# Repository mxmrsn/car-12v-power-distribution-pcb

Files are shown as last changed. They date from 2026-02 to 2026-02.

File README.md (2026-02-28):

# Car 12V Power Distribution PCB
12V distribution block for supporting interior automotive (12V+) accessories. Note: Some accesories mentioned such as dashcam and charger have downstream 5V regulators. Molex PicoSpox contacts (0874370231) are rated for 3A each with 24AWG wire.

## Notes
- Footprints are Molex PicoSpoX-style SMD 1.5mm pitch footprints. 
- Inputs:
  - `12V+` (+12V battery)
  - `12V_ACC` (+12V accessory)
  - `GND` (ground)
- Output (3-pin): `+12V`, `+12V_ACC`, `GND`
- Output (4-pin): `+12V`, `+12V_ACC`, `+12V_HEADLIGHT`, `GND`
- PCB uses 40 mil traces for all nets. 
- Board outline is 1.5" x 2".
- 3D printed caddy will require strain relief and a mobile loop of wire to move with the opening/closing of the drawer.

## Schematic
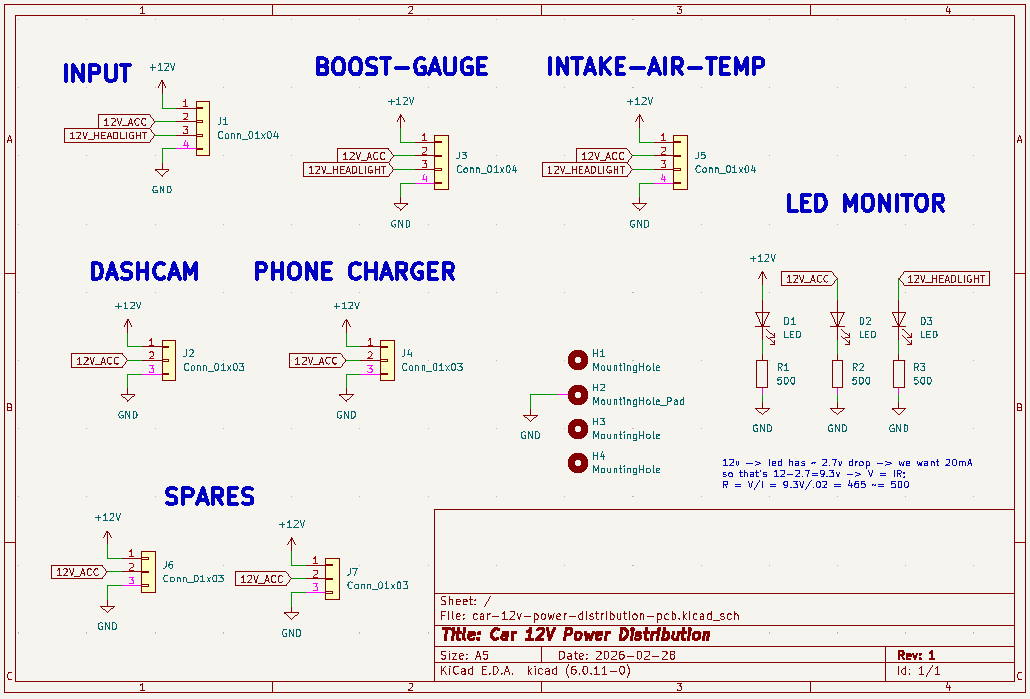
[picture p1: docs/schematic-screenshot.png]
Schematic


## PCB Layout
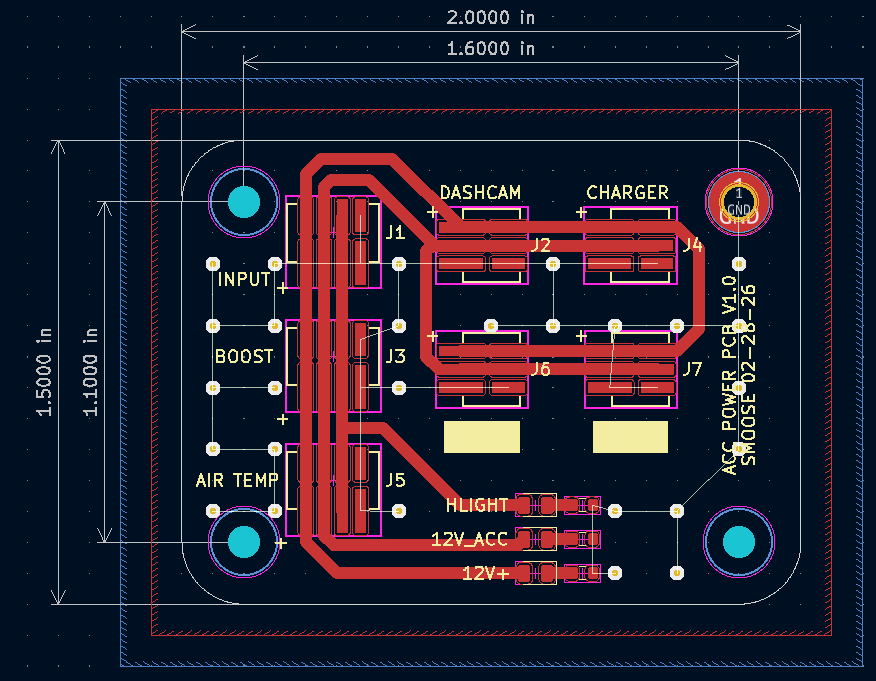
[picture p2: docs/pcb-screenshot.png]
Layout


## 3D Model
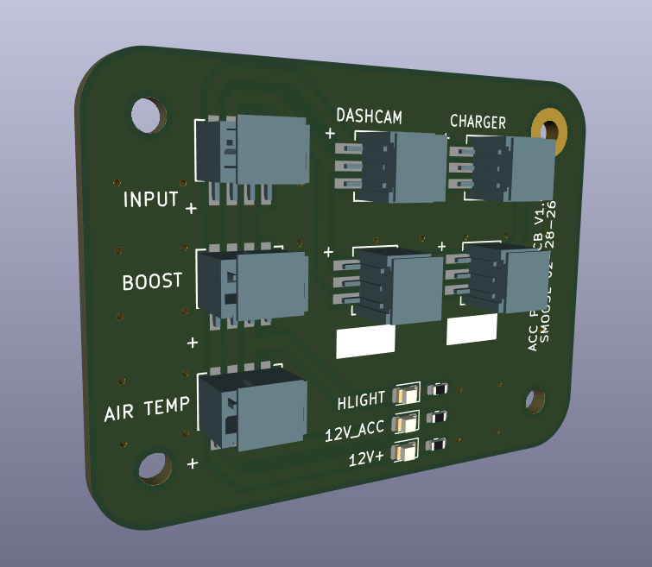
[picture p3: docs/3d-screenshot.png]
3D


## BOM
- 3-pin connector [Molex #0874370363](https://www.digikey.com/en/products/detail/molex/0874370363/2834835)
- 4-pin connector [Molex 0874370473](https://www.digikey.com/en/products/detail/molex/0874370473/2421923)

Mating connectors (cable-side):
- 3-pin housing [Molex #0874390300](https://www.digikey.com/en/products/detail/molex/0874390300/561766)
- 4-pin housing [Molex #0874390400](https://www.digikey.com/en/products/detail/molex/0874390400/561767)
- Molex PicoSpox Contact [Molex #0874210000](https://www.digikey.com/en/products/detail/molex/0874210000/561764)

## Reference
- [Molex PicoSpox Wire-to-Board Connectors](https://www.digikey.com/en/product-highlight/m/molex-connector/pico-spox-wire-to-board-connector-system)

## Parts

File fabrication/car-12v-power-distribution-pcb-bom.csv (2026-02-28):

Comment | Designator | Footprint | LCSC Part #
LED Light emitting diode | D1,D2,D3 | LED_0603_1608Metric | C2286
Conn_01x04 Generic connector, single row, 01x04, script generated (kicad-library-utils/schlib/autogen/connector/) | J1,J3,J5 | CONN_874370231-SD_04_MOL | C588581
Conn_01x03 Generic connector, single row, 01x03, script generated (kicad-library-utils/schlib/autogen/connector/) | J2,J4,J6,J7 | CONN_874370231-SD_03_MOL | C17393004
500 Resistor | R1,R2,R3 | R_0603_1608Metric | C860931

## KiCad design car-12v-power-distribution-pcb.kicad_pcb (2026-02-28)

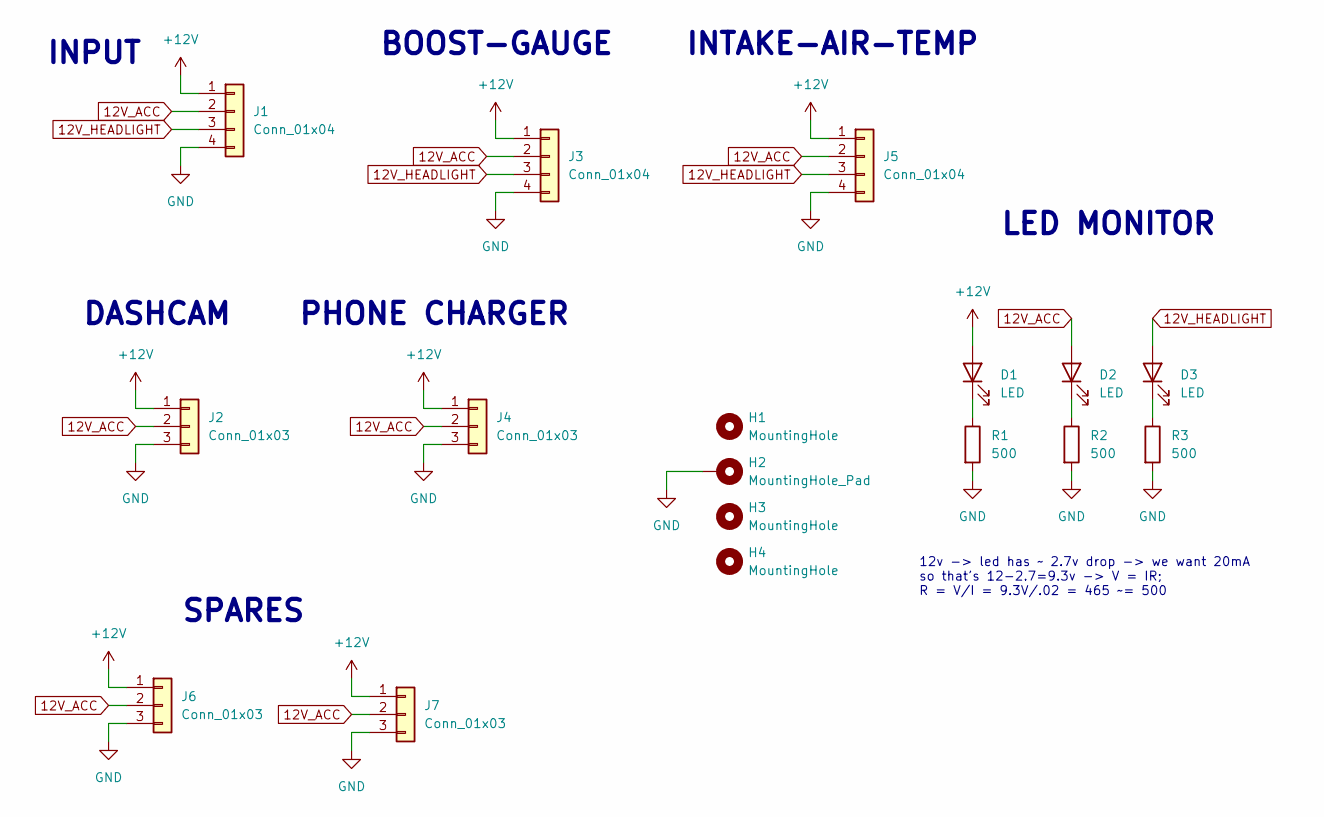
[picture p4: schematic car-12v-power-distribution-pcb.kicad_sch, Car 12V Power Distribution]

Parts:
D1, D2, D3: LED; LED_0603_1608Metric; LCSC C2286
H1, H3, H4: MountingHole; MountingHole_2.7mm_M2.5
H2: MountingHole_Pad; MountingHole_2.5mm_Pad_TopBottom
J1, J3, J5: Conn_01x04; CONN_874370231-SD_04_MOL; LCSC C588581
J2, J4, J6, J7: Conn_01x03; CONN_874370231-SD_03_MOL; LCSC C17393004
R1, R2, R3: 500; R_0603_1608Metric; LCSC C860931

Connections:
12V_ACC: D2.2 (A), J1.2, J2.2, J3.2, J4.2, J5.2, J6.2, J7.2
12V_HEADLIGHT: D3.2 (A), J1.3, J3.3, J5.3
+12V: D1.2 (A), J1.1, J2.1, J3.1, J4.1, J5.1, J6.1, J7.1
GND: H2.1, J1.4, J2.3, J3.4, J4.3, J5.4, J6.3, J7.3, R1.2, R2.2, R3.2
unnamed: D1.1 (K), R1.1
unnamed: D2.1 (K), R2.1
unnamed: D3.1 (K), R3.1

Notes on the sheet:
12v -> led has ~ 2.7v drop -> we want 20mA so that's 12-2.7=9.3v -> V = IR; R = V/I = 9.3V/.02 = 465 ~= 500
PHONE CHARGER
SPARES
INTAKE-AIR-TEMP
INPUT
DASHCAM
LED MONITOR
BOOST-GAUGE

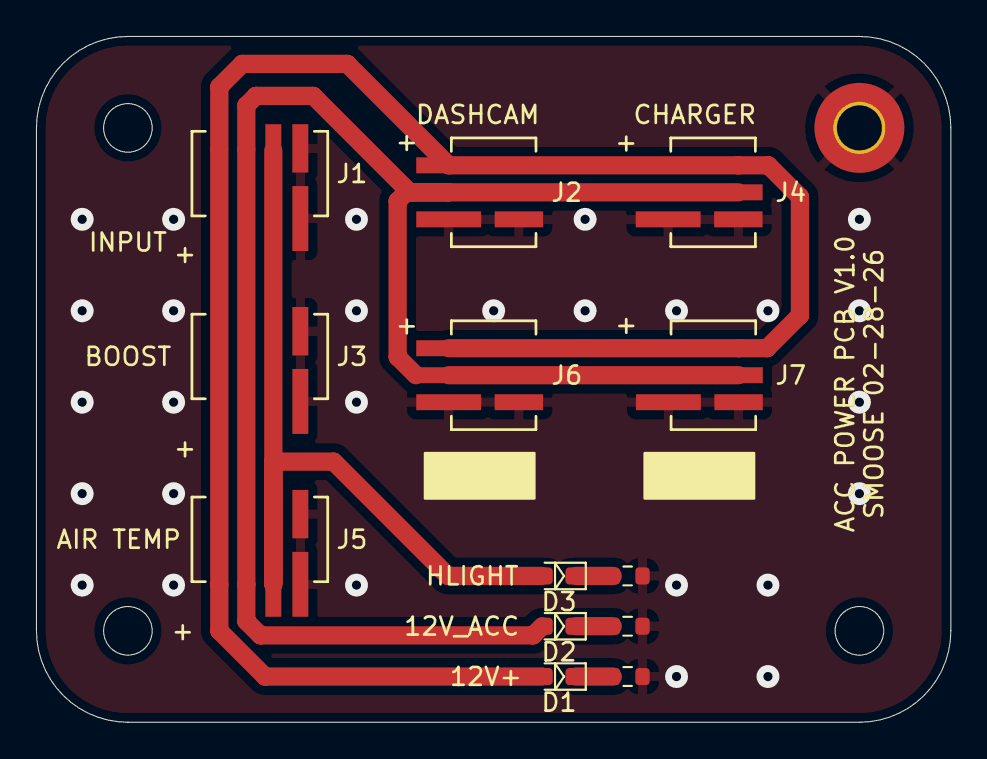
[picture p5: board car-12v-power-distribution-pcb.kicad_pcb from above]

Board: 2 copper layers, 50.8 x 38.1 mm, 17 parts (0 on the bottom side), 7 nets.

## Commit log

2026-02-28 Initial 12V distribution PCB
    [vw-gti-12v-distribution.kicad_pcb, vw-gti-12v-distribution.kicad_sch]
2026-02-28 Switch to SMD PicoSpoX and add ACC + extra outputs
    [vw-gti-12v-distribution.kicad_pcb, vw-gti-12v-distribution.kicad_sch]
2026-02-28 Downgrade schematic format for KiCad 6
    [car-12v-power-distribution-pcb.kicad_sch]
2026-02-28 Remove hide flags for KiCad 6 compatibility
    [car-12v-power-distribution-pcb.kicad_sch]
2026-02-28 Strip footprint properties for KiCad 6 PCB
    [car-12v-power-distribution-pcb.kicad_pcb]
2026-02-28 Reset to blank KiCad 6 schematic and PCB
    [car-12v-power-distribution-pcb.kicad_pcb, car-12v-power-distribution-pcb.kicad_sch]
2026-02-28 version 1.0
    [car-12v-power-distribution-pcb.kicad_pcb, car-12v-power-distribution-pcb.kicad_sch]
2026-02-28 Add schematic and layout screenshots to README
2026-02-28 Add gerbers archive
2026-02-28 added .gitignore and footprints/
2026-02-28 updated grounding hole
    [car-12v-power-distribution-pcb.kicad_pcb, car-12v-power-distribution-pcb.kicad_sch]
2026-02-28 added bom and cpl files
    [car-12v-power-distribution-pcb-bom.csv, car-12v-power-distribution-pcb.kicad_pcb, car-12v-power-distribution-pcb.kicad_sch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]
